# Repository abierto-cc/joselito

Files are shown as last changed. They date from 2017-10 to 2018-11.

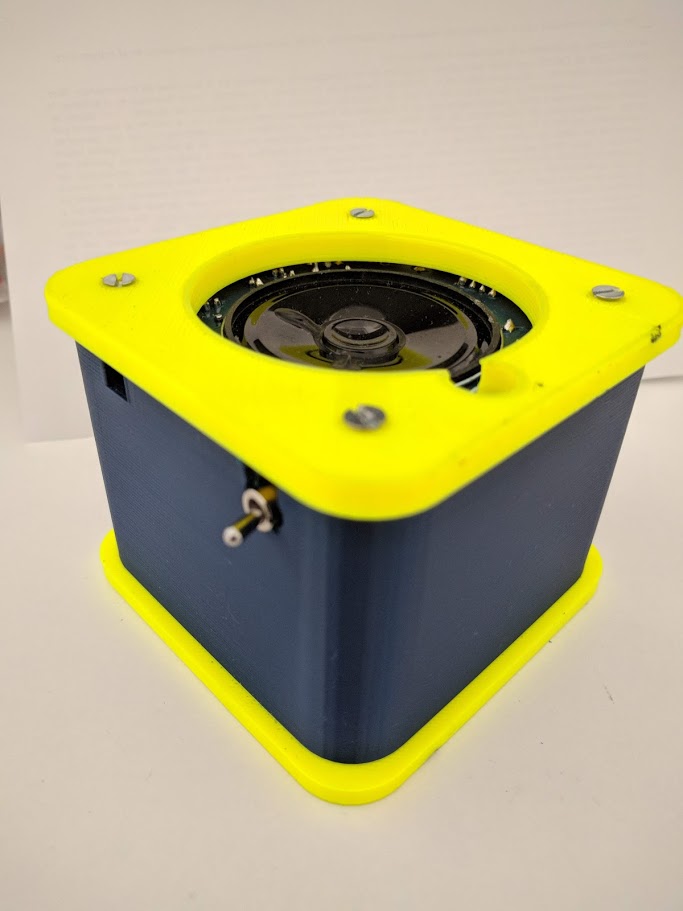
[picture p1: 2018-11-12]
embebido/hardware/3Dmodel/IMG_20180724_153458.jpg

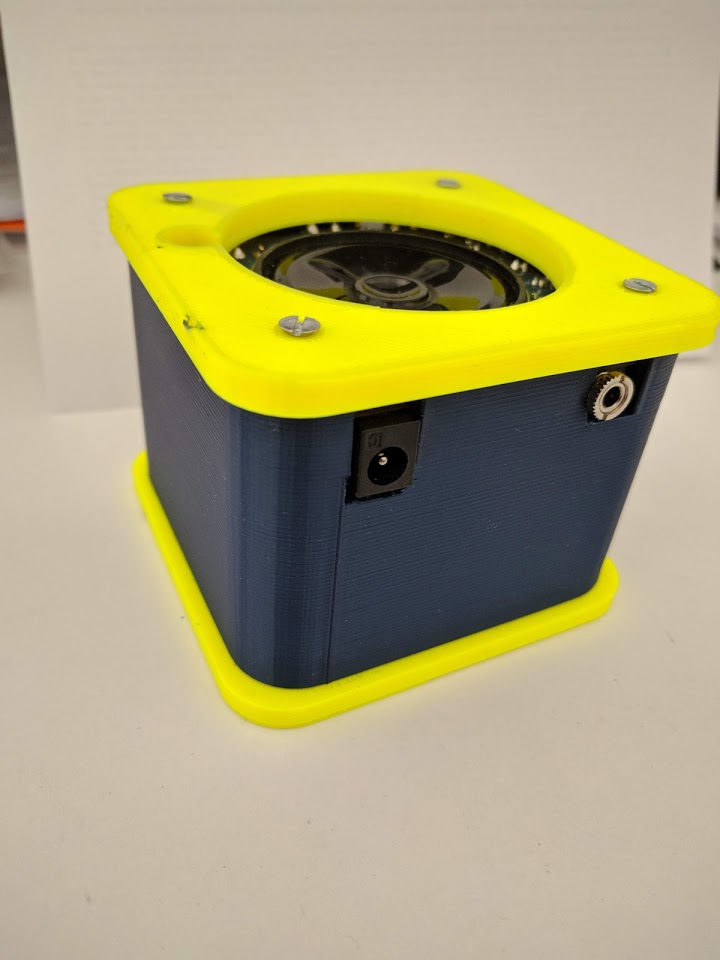
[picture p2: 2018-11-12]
embebido/hardware/3Dmodel/IMG_20180724_153512.jpg

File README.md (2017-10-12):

# joselito
Repositorio del único amplificador que hace justicia a una de las estrellas más brillantes de la canción en habla hispana ... ¡Joselito!

Diseñado en Suecia con amor para toda la galaxia

# consigue tu kit

Si quieres conseguir el kit para montarlo, visita: https://abierto.cc/shop

# instrucciones de montaje

Puedes ver las instrucciones de montaje paso a paso en: https://sites.google.com/abierto.cc/joselito-mini

Puedes ver las instrucciones de montaje paso a paso en: https://sites.google.com/abierto.cc/joselito-embebido

# créditos

Joselito ... que nos inspira y nos guía desde las profundidades de YouTube

# autores

D. Cuartielles at abierto.cc (idea)

J. Garcia at abierto.cc (diseño en KiCAD para el Joselito mini, Joselito embebido y el Joselito Princesa Bultos)

L. Balboa at abierto.cc (gráficos)

# menciones

* Joselito ... es que no podemos dejar de pensar en el, sólo mirad esto: https://www.youtube.com/watch?v=RQnSKqZ-XVg ¿no os pone los pelos de punta?

# licencia para hardware y documentation

<br /><span xmlns:dct="http://purl.org/dc/terms/" href="http://purl.org/dc/dcmitype/Dataset" property="dct:title" rel="dct:type">Fenderino Arducaster</span> by <a xmlns:cc="http://creativecommons.org/ns#" href="https://abierto.cc" property="cc:attributionName" rel="cc:attributionURL">Proyecto Abierto</a> is licensed under a <a rel="license" href="http://creativecommons.org/licenses/by-nc-sa/4.0/">Creative Commons Reconocimiento-NoComercial-CompartirIgual 4.0 Internacional License</a>.<br />Creado a partir de la obra en <a xmlns:dct="http://purl.org/dc/terms/" href="https://github.com/abierto-cc/fenderino" rel="dct:source">https://github.com/abierto-cc/fenderino</a>

# licencia para código de ejemplos

El código está liberado bajo licencia GPLv3, se recomienda leer el fichero de licencia para más información

# abierto

Abierto es una inciativa de D. Cuartielles gracias a la generosa aportación de la Fundación PUIG por intermediación de la Fundación Ashoka de cara a contribuir a la creación de material educativo de libre acceso y circulación

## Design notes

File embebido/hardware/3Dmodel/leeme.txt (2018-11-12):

EL diseño se ha realizado con al herramienta libre FreeCAD.

Hay varios modelos. Se han debido hacer distintas pruebas para que encajaran los componenetes de jack, interruptor , etc.
Al final he tenido que limar para que encajaran bien.

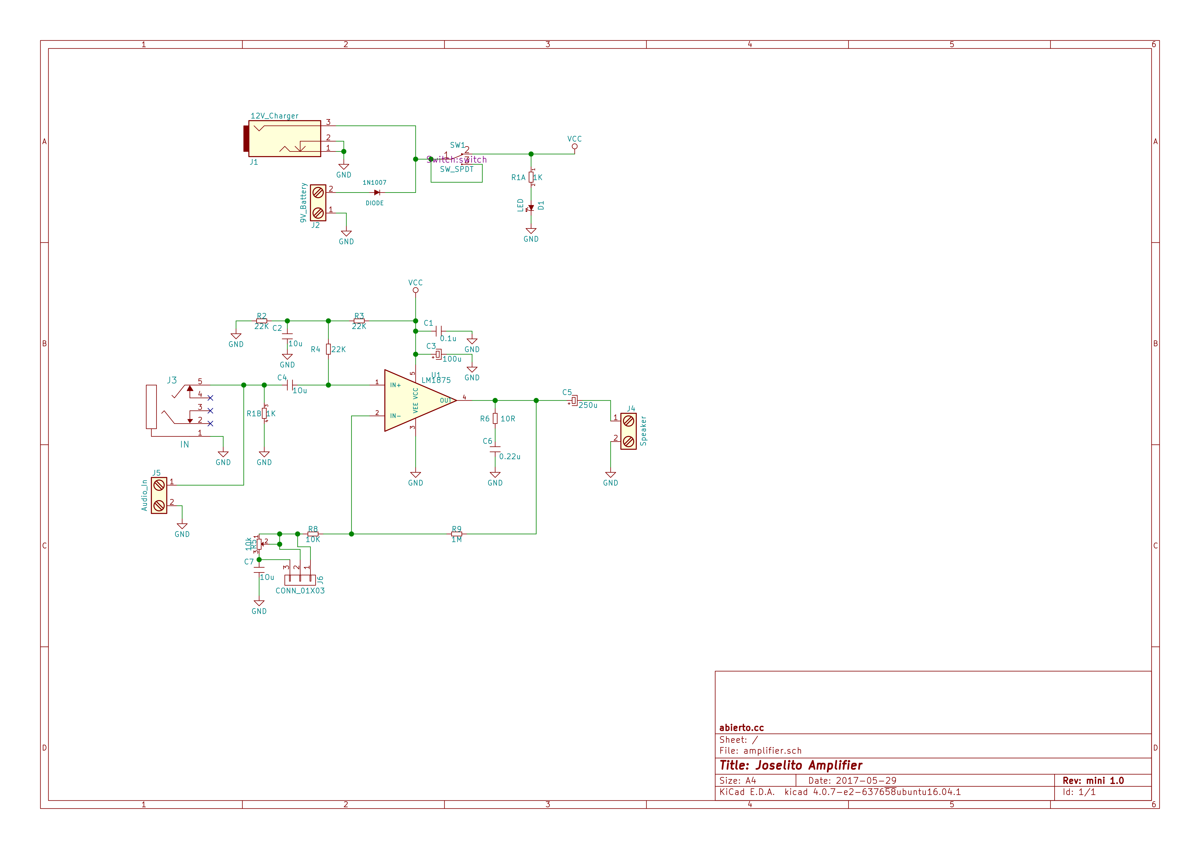
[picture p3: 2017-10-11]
mini/hardware/pdf/Joselito_mini_schematics.png

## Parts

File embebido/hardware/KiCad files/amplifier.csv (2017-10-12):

Reference | Value | Footprint | Datasheet
J2 | 9V_Battery | Connect:bornier2
J1 | 12V_Charger | Connect:BARREL_JACK
U1 | LM1875 | TO_SOT_Packages_THT:TO-220-5_Pentawatt_Multiwatt-5_Vertical_StaggeredType1
J3 | IN | AV_Conn:jack_huella
1N1007 | DIODE | Diodes_ThroughHole:D_DO-41_SOD81_P2.54mm_Vertical_AnodeUp
D1 | LED | LEDs:LED_D3.0mm
C4 | 1Ou | Capacitors_ThroughHole:C_Disc_D5.0mm_W2.5mm_P5.00mm
R4 | 22K | Resistors_ThroughHole:R_Axial_DIN0204_L3.6mm_D1.6mm_P1.90mm_Vertical
R3 | 22K | Resistors_ThroughHole:R_Axial_DIN0204_L3.6mm_D1.6mm_P1.90mm_Vertical
R2 | 22K | Resistors_ThroughHole:R_Axial_DIN0204_L3.6mm_D1.6mm_P1.90mm_Vertical
C1 | 0.1u | Capacitors_ThroughHole:C_Disc_D5.0mm_W2.5mm_P5.00mm
C2 | 10u | Capacitors_ThroughHole:C_Disc_D5.0mm_W2.5mm_P5.00mm
R6 | 10R | Resistors_ThroughHole:R_Axial_DIN0309_L9.0mm_D3.2mm_P12.70mm_Horizontal
C6 | 0.22u | Capacitors_ThroughHole:C_Rect_L7.2mm_W5.5mm_P5.00mm_FKS2_FKP2_MKS2_MKP2
C3 | 100u | Capacitors_ThroughHole:CP_Radial_D6.3mm_P2.50mm
C5 | 250u | Capacitors_ThroughHole:CP_Radial_D10.0mm_P5.00mm
R9 | 1M | Resistors_ThroughHole:R_Axial_DIN0204_L3.6mm_D1.6mm_P1.90mm_Vertical
R8 | 10K | Resistors_ThroughHole:R_Axial_DIN0204_L3.6mm_D1.6mm_P1.90mm_Vertical
C7 | 1Ou | Capacitors_ThroughHole:C_Disc_D5.0mm_W2.5mm_P5.00mm
R1 | 1K | Resistors_ThroughHole:R_Array_SIP4
J4 | Speaker | Connect:bornier2
J5 | Audio_In | Connect:bornier2
R5 | 10k | Potentiometers:Potentiometer_Trimmer_Vishay_T73YP_Horizontal
SW1 | SW_SPDT | Switch:switch

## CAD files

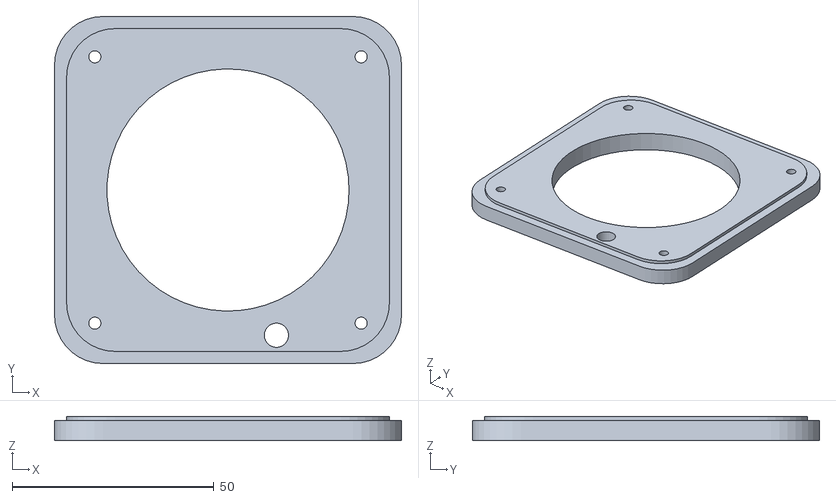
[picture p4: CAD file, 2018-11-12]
embebido/hardware/3Dmodel/tapajoselito.stl
86.0 x 86.0 x 6.00

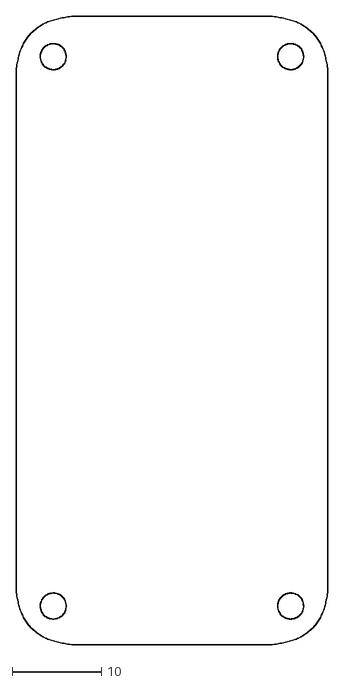
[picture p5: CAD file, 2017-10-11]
mini/hardware/Silks/amp_dim_V2.dxf
34.9 x 70.4

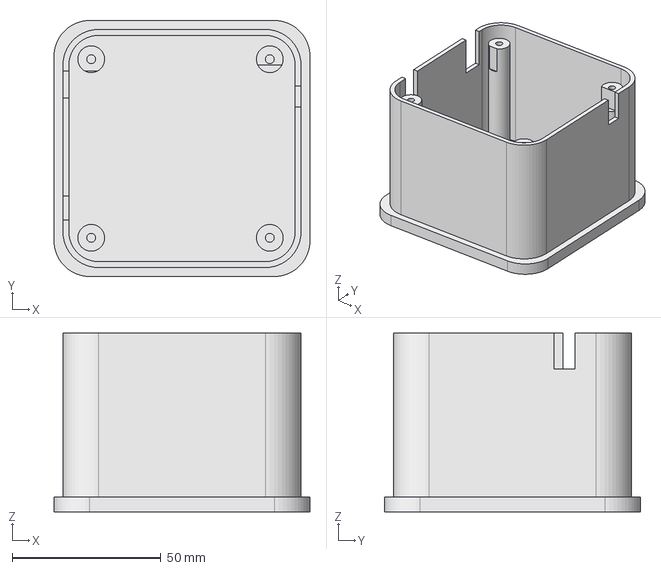
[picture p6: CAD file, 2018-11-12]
embebido/hardware/3Dmodel/JoselitoBOX_V2_2.fcstd
86.0 x 86.0 x 60.0 mm

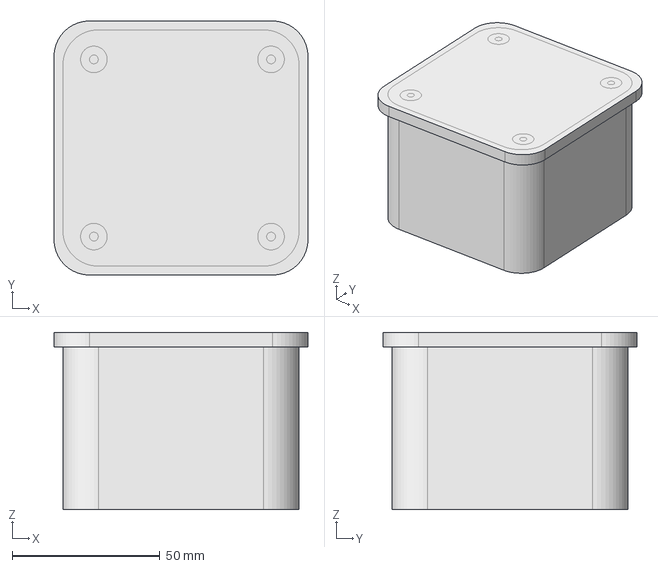
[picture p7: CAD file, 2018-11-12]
embebido/hardware/3Dmodel/JoselitoBOX_V2_1withoutholes.fcstd
86.0 x 86.0 x 60.0 mm

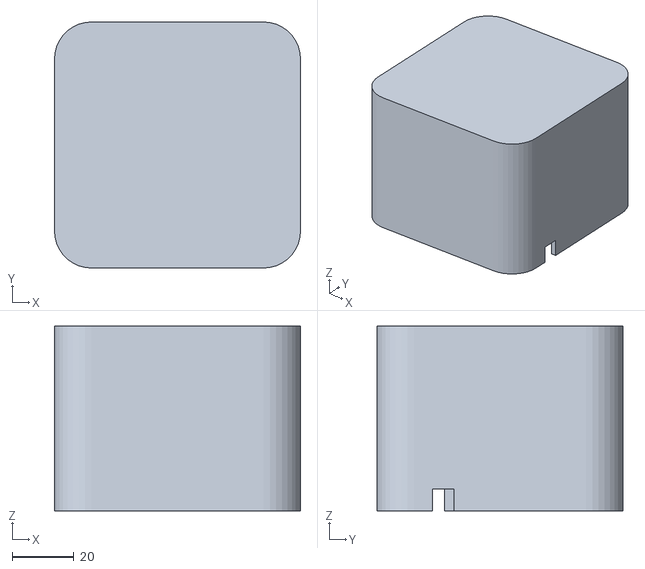
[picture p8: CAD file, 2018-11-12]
embebido/hardware/3Dmodel/boxspeakers.stl
80.0 x 80.0 x 60.0

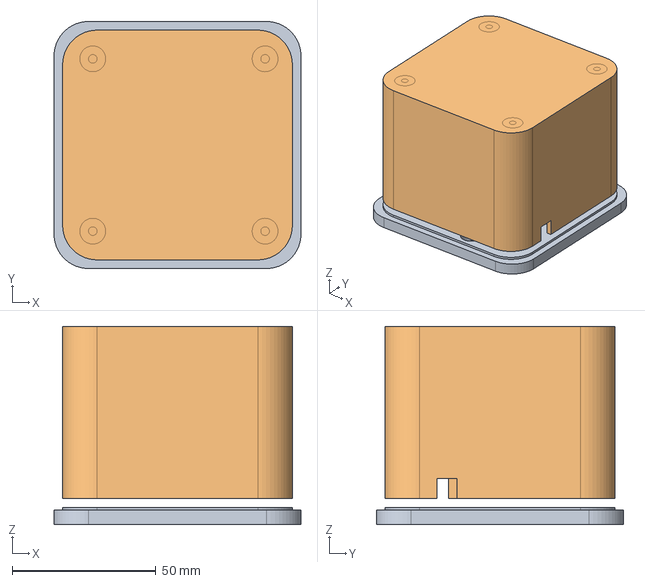
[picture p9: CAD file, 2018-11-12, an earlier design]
embebido/hardware/3Dmodel/JoselitoBOX_V2.fcstd
86.0 x 86.0 x 69.0 mm
frontspeaker

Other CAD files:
embebido/hardware/3Dmodel/frontspeaker.fcstd
embebido/hardware/3Dmodel/boxV2_2.stl
embebido/hardware/3Dmodel/boxV2_1.stl
embebido/hardware/3Dmodel/JoselitoBOX_V2_1.fcstd
embebido/hardware/3Dmodel/frontspeaker.stl

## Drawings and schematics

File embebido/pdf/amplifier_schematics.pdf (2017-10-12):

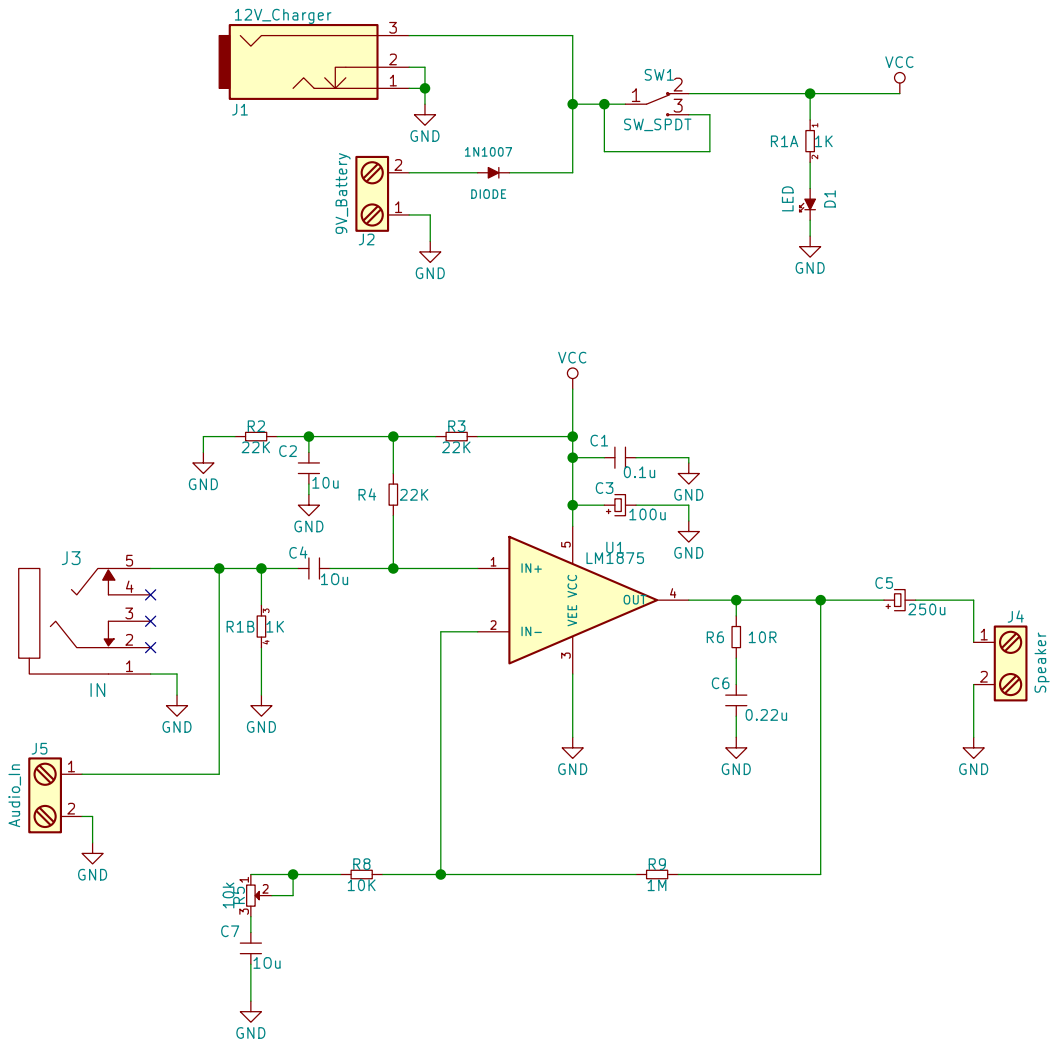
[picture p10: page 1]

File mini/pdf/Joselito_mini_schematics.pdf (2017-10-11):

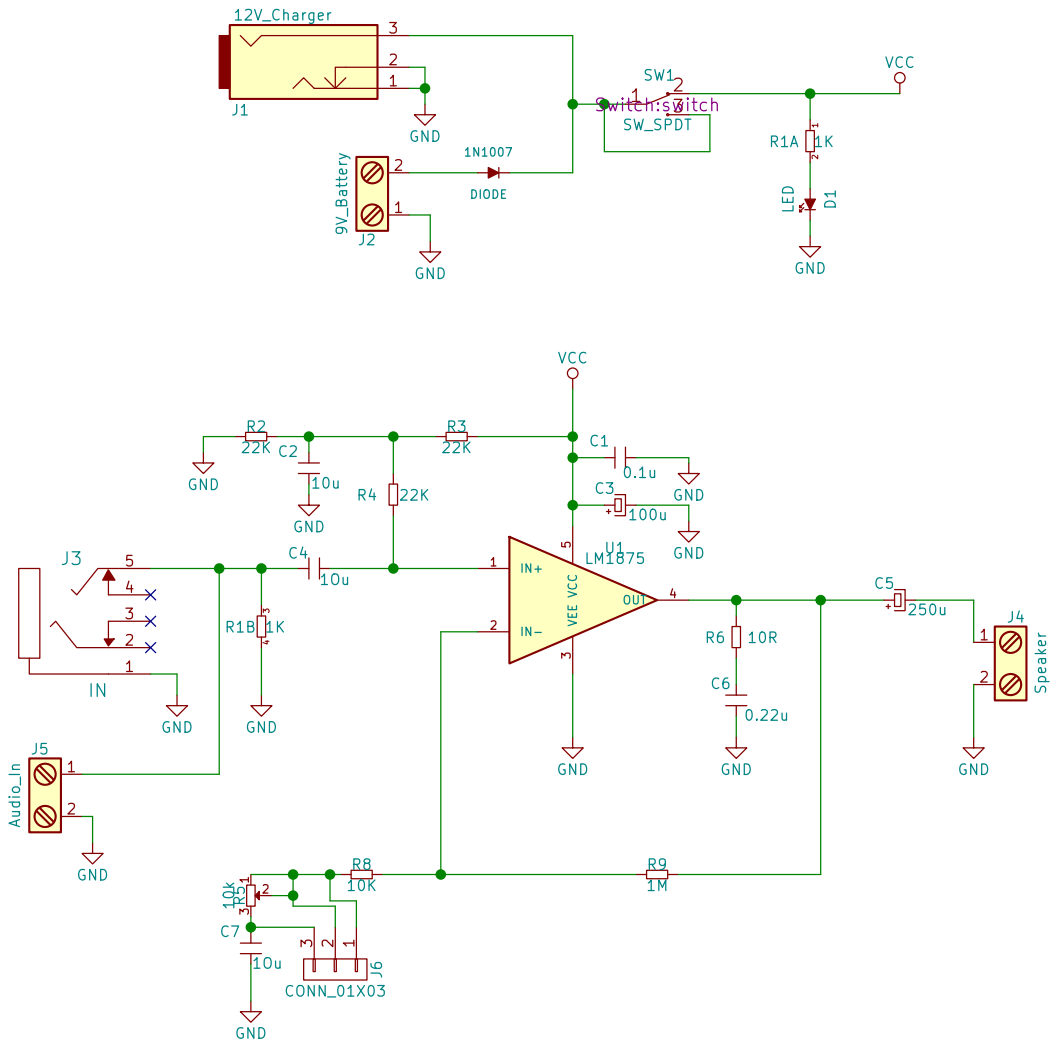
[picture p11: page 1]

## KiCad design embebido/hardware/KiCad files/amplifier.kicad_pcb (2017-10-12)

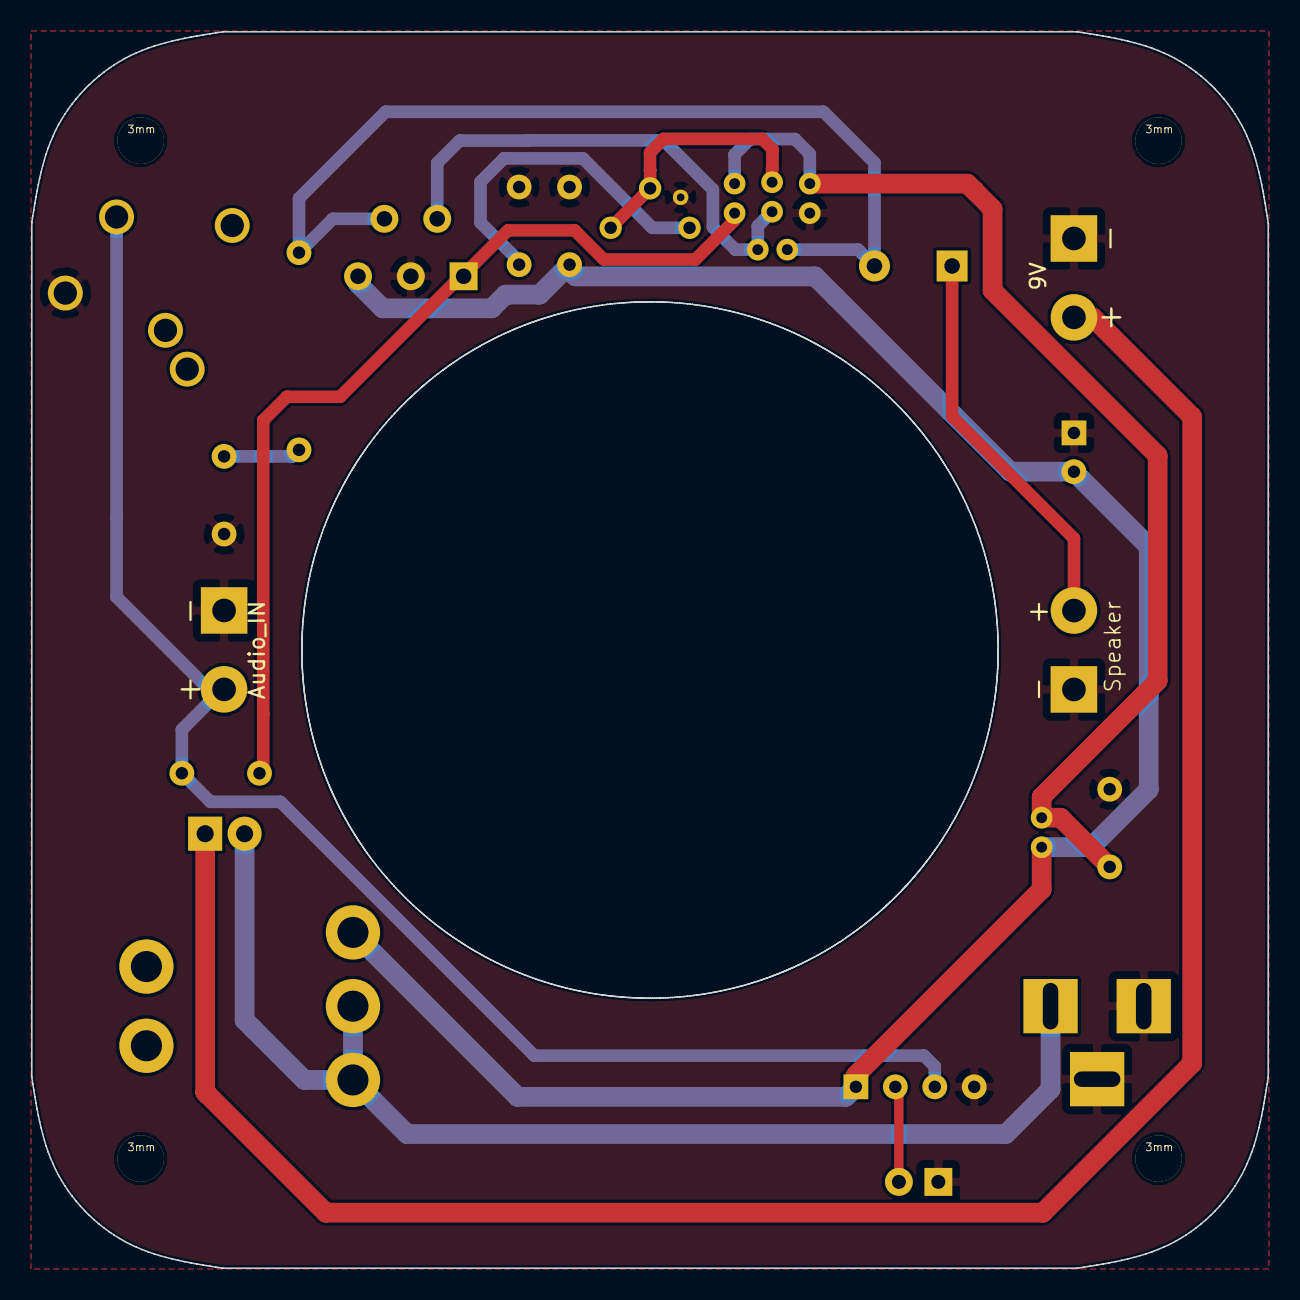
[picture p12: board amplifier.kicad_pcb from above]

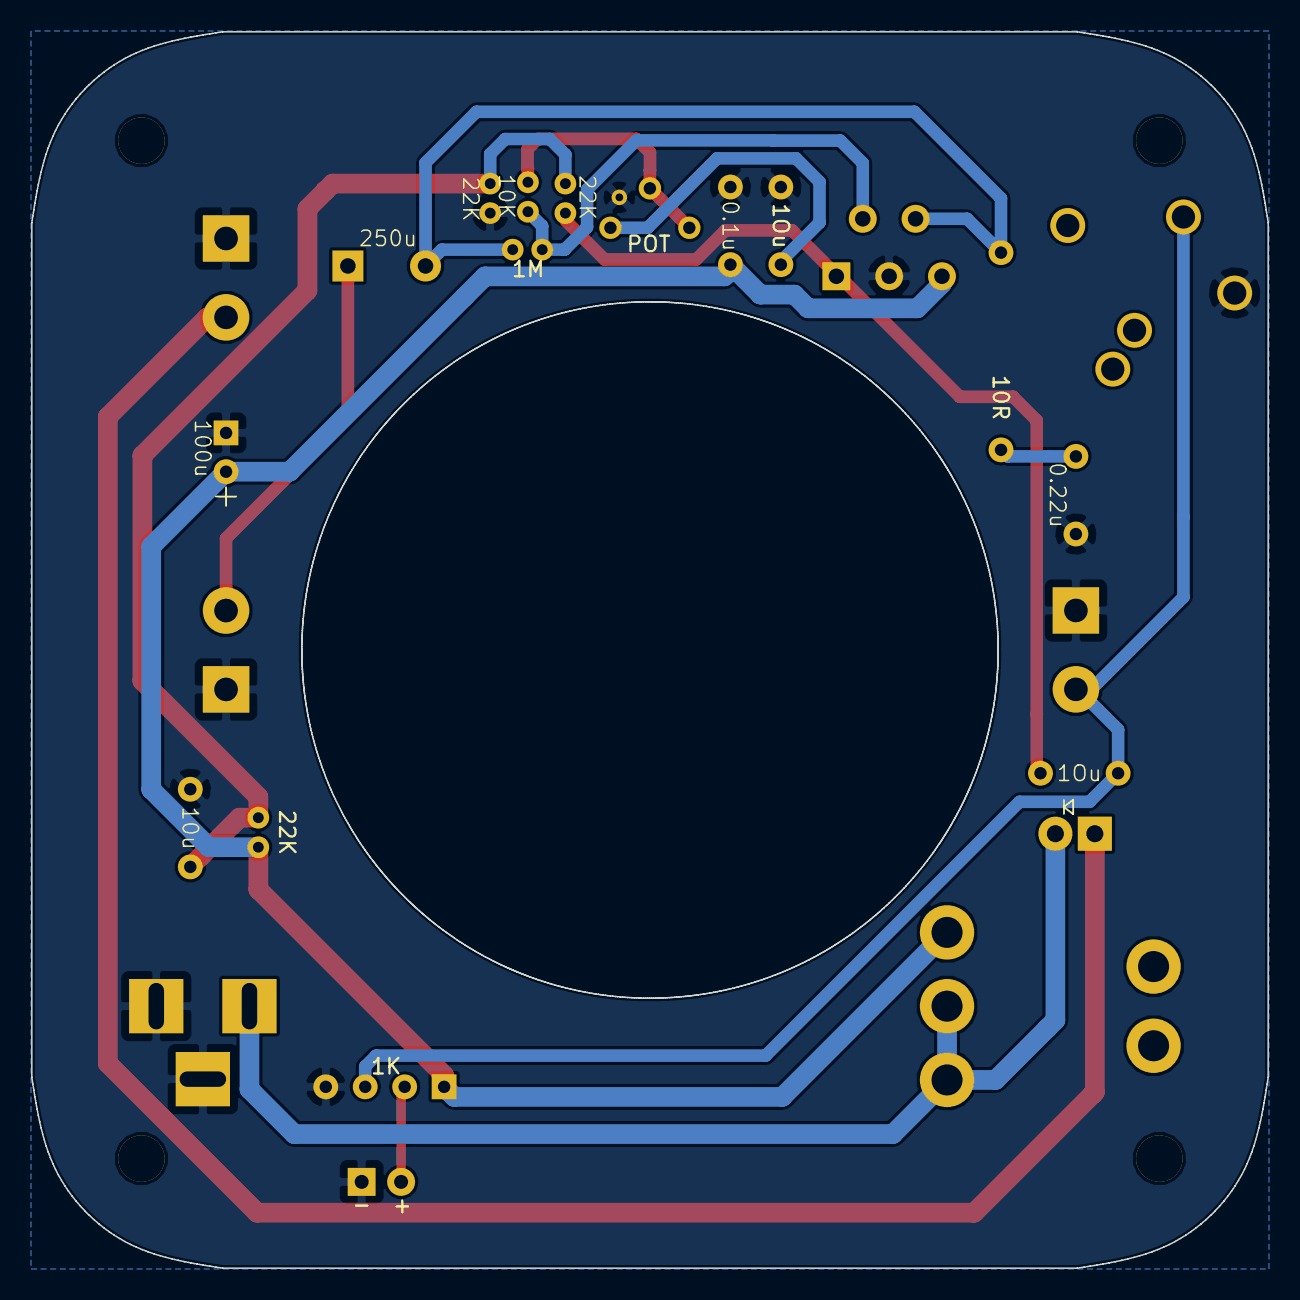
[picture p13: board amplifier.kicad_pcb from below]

Board: 2 copper layers, 79.6 x 79.6 mm, 24 parts (22 on the bottom side), 14 nets.

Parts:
1N1007: DIODE; D_DO-41_SOD81_P2.54mm_Vertical_AnodeUp
C1: 0.1u; C_Disc_D5.0mm_W2.5mm_P5.00mm
C2: 10u; C_Disc_D5.0mm_W2.5mm_P5.00mm
C3: 100u; CP_Radial_D6.3mm_P2.50mm
C4, C7: 1Ou; C_Disc_D5.0mm_W2.5mm_P5.00mm
C5: 250u; CP_Radial_D10.0mm_P5.00mm
C6: 0.22u; C_Rect_L7.2mm_W5.5mm_P5.00mm_FKS2_FKP2_MKS2_MKP2
D1: LED; LED_D3.0mm
J1: 12V_Charger; BARREL_JACK
J2: 9V_Battery; bornier2
J3: IN; jack_huella
J4: Speaker; bornier2
J5: Audio_In; bornier2
R1: 1K; R_Array_SIP4
R2, R3, R4: 22K; R_Axial_DIN0204_L3.6mm_D1.6mm_P1.90mm_Vertical
R5: 10k; Potentiometer_Trimmer_Vishay_T73YP_Horizontal
R6: 10R; R_Axial_DIN0309_L9.0mm_D3.2mm_P12.70mm_Horizontal
R8: 10K; R_Axial_DIN0204_L3.6mm_D1.6mm_P1.90mm_Vertical
R9: 1M; R_Axial_DIN0204_L3.6mm_D1.6mm_P1.90mm_Vertical
SW1: SW_SPDT; switch
U1: LM1875; TO-220-5_Pentawatt_Multiwatt-5_Vertical_StaggeredType1

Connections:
GND: C1.2, C2.1, C3.2, C6.1, C7.1, D1.1, J1.1, J1.2, J2.1, J3.1, J4.2, J5.2, R1.4, R2.2, U1.3
unnamed: 1N1007.1, J2.2
unnamed: 1N1007.2, J1.3, SW1.2, SW1.3
unnamed: C2.2, R2.1, R3.2, R4.1
unnamed: C4.1, R4.2, U1.1
unnamed: C4.2, J3.5, J5.1, R1.3
unnamed: C5.1, R6.1, R9.1, U1.4
unnamed: C5.2, J4.1
unnamed: C6.2, R6.2
unnamed: C7.2, R5.3
unnamed: D1.2, R1.2
unnamed: R5.1, R5.2, R8.2
unnamed: R8.1, R9.2, U1.2
VCC: C1.1, C3.1, R1.1, R3.1, SW1.1, U1.5

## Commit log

2017-10-04 Actualizado el Readme, amigos!
2017-10-04 LICENCIA ... para que luego no digan
2017-10-11 LICENCIA ... para que luego no digan
    Esqemático, PCB y gerbers del Joselito
2017-10-11 Archivos hardware
    Esquemático, PCB y Gerbers del Joselito
    [amp_dim_V2.dxf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]
2017-10-11 Archivos Hardware
    Esquemáticos, PCB y Silks
    [amplifier-B.Cu.gbl, amplifier-B.Mask.gbs, amplifier-B.SilkS.gbo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]
2017-10-12 Amplificador Joselito
    [amp_dim_V2.dxf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]
2017-10-12 Esquematicos
    Archivos png y pdf de los esquemáticos del Joselito mini
    [amp_dim_V2.dxf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]
2017-10-12 Archivos KiCad
    Archivos de diseño en KiCad del Joselito mini
    [amplifier.csv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]
2017-10-12 Esquemáticos
    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
2017-10-12 Gerbers
    Archivos para fabricación de PCB del Joselito mini
    [amplifier-B.Cu.gbl, amplifier-B.Mask.gbs, amplifier-B.SilkS.gbo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]
2017-10-12 Dimensiones
    Archivos de borde de placa en formato de componente para KiCad
    [amp_dim_V2.dxf]
2017-10-12 Esquemáticos
    Archivos png y pdf de los esquemáticos del Joselito embebido
2017-10-12 Archivos KiCad
    Archivos de diseño en KiCad del Joselito embebido
    [amplifier.csv, amplifier.kicad_pcb, amplifier.sch]
2017-10-12 Gerbers
    Archivos para fabricación de PCB del Joselito embebido
    [amplifier-B.Cu.gbl, amplifier-B.Mask.gbs, amplifier-B.SilkS.gbo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]
2017-10-12 Instrucciones de montaje
    Añadidas las instrucciones de montaje para el joselito-mini y el joselito-embebido
2017-10-12 Actualizado el readme... Amigos!!
    Añadidas las instrucciones de montaje para el Joselito-mini y el Joselito-embebido
2017-10-19 BOM Joselito mini
    [BOM_Joselito_mini.csv]
2017-10-19 BOM Joselito embebido
    [BOM_Joselito_embebido.csv]
2017-10-31 Esquema Joselito mini
    Archivos png y pdf del esquema del Joselito mini
    [BOM_Joselito_embebido.csv]
